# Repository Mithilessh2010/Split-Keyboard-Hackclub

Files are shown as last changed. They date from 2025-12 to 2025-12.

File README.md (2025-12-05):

# Split Keyboard Project

This repository contains the full design for my custom split keyboard, including the PCB, schematic, case files, and bill of materials. Everything needed to build or modify the keyboard is documented here in a clear and approachable format.

## Overview

The keyboard is built around the Seeed XIAO nRF52840 microcontroller, Kailh Choc low profile switches, SOD-123 diodes, and a simple two-piece 3D printed case. The goal of the project is to create a compact split keyboard that is straightforward to assemble and easy to modify.

## Images

All images for the project can be found in the Images folder.

### CAD View (Final, just unmated for clarity)
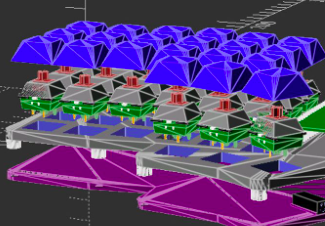
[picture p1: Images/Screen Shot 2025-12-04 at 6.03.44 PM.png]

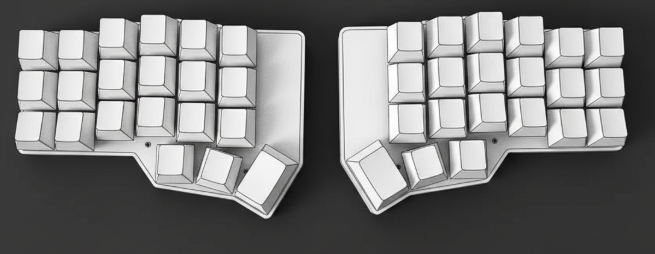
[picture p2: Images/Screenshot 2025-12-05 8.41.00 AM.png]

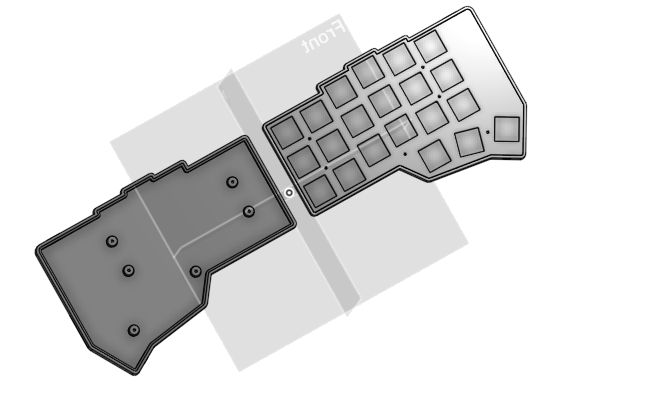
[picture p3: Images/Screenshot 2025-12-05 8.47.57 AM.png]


### PCB Layout
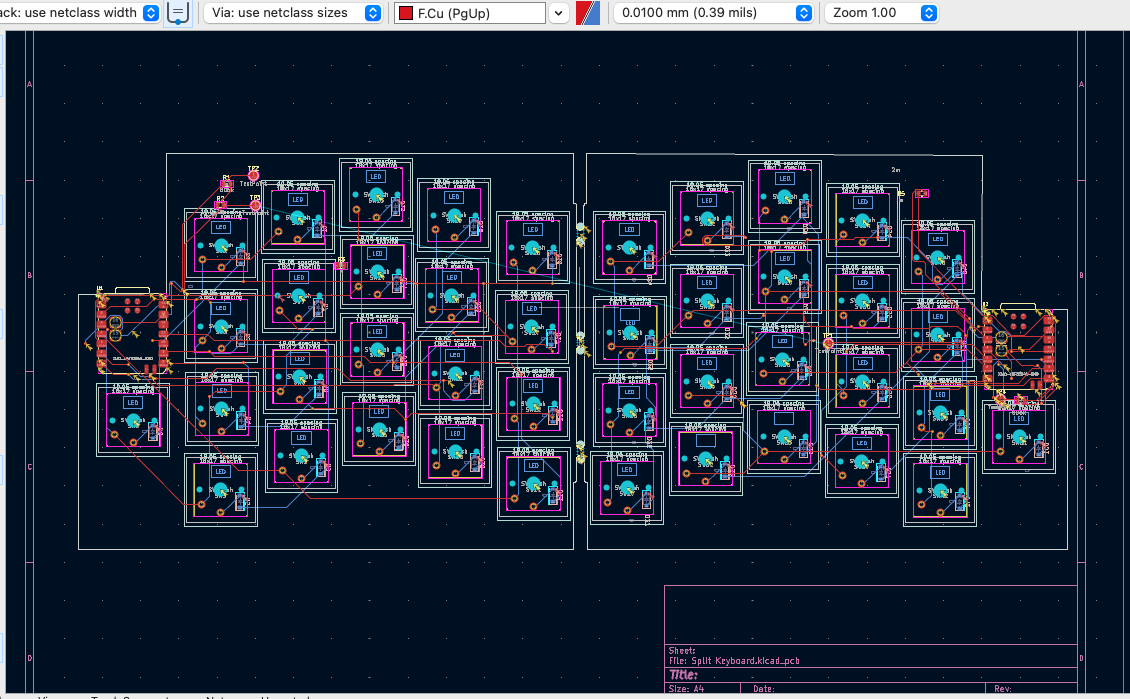
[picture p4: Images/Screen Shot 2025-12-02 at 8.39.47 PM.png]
PCB


### Schematics
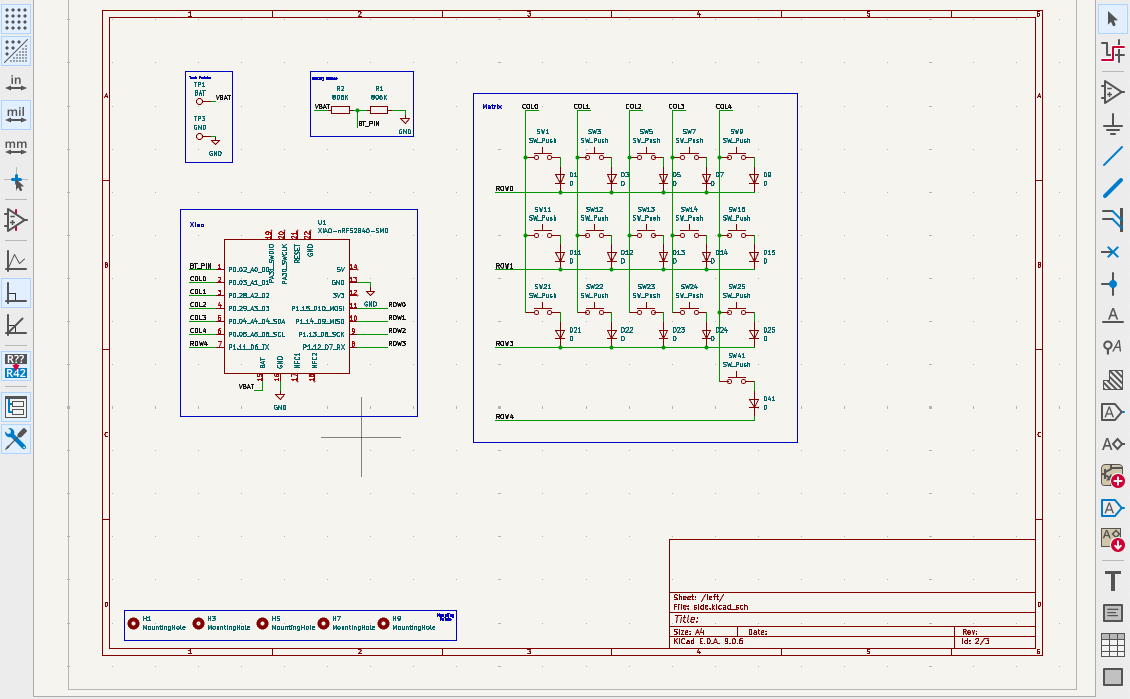
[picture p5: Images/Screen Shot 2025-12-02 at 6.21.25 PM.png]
Schematics


## Bill of Materials

Below is the full set of components used in the keyboard.

### BOM Table

| Category | Part Description | Footprint | Quantity |
|---|---|---|---|
| Resistors | 806k ohm | R_0805_2012Metric | 2 |
| | 2M ohm | R_0805_2012Metric | 2 |
| | R (0 ohm or jumper) | R_0805_2012Metric | 1 |
| Diodes | SOD-123 diode | D_SOD-123 | 42 |
| Microcontrollers | Seeed XIAO nRF52840 | modified-XIAO-nRF52840-SMD | 2 |
| Switches | Kailh Choc V1 switches | SW_choc_v1_1u | 41 |
| Test Points | Test pad | TestPoint_Pad_D2.0mm | 4 |

## 3D Printed Parts

The keyboard uses two printed case parts.

- Top case  
- Bottom case  

Both parts are sized so the PCB fits properly without forcing anything into place.

## Assembly Instructions

1. Install and solder all diodes first. These sit flat on the PCB.
2. Solder all resistors.
3. Insert and solder all Kailh Choc switches.
4. Attach both XIAO nRF52840 modules and verify each pin is properly soldered.
5. Inspect the board and test the key matrix.
6. Place the PCB into the printed case and complete the assembly.

## Cost Breakdown

### AliExpress Order
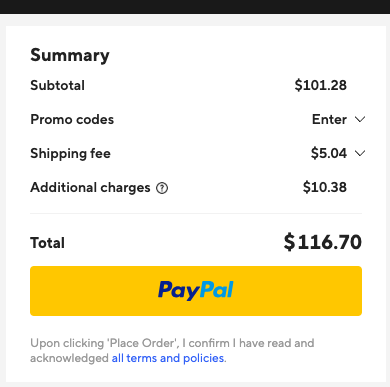
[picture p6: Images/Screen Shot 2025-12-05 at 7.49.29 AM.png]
ALIEXPRESSTOTAL

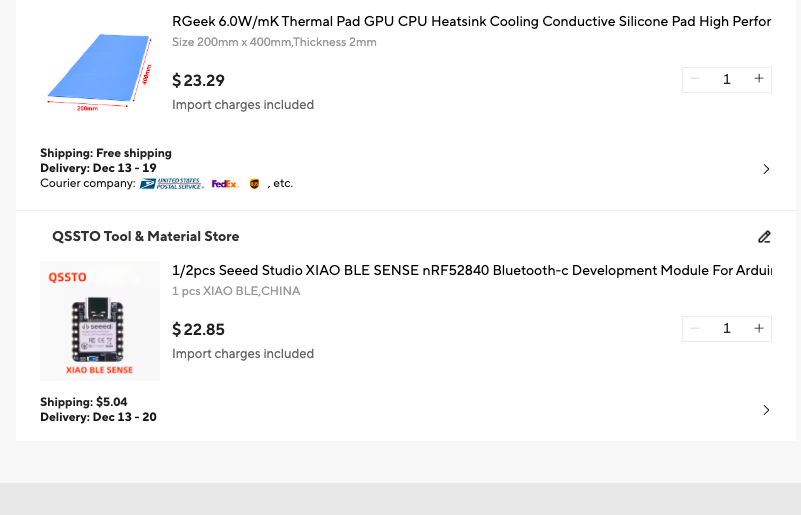
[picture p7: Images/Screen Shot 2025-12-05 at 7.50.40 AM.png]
ALIEXPRESS1

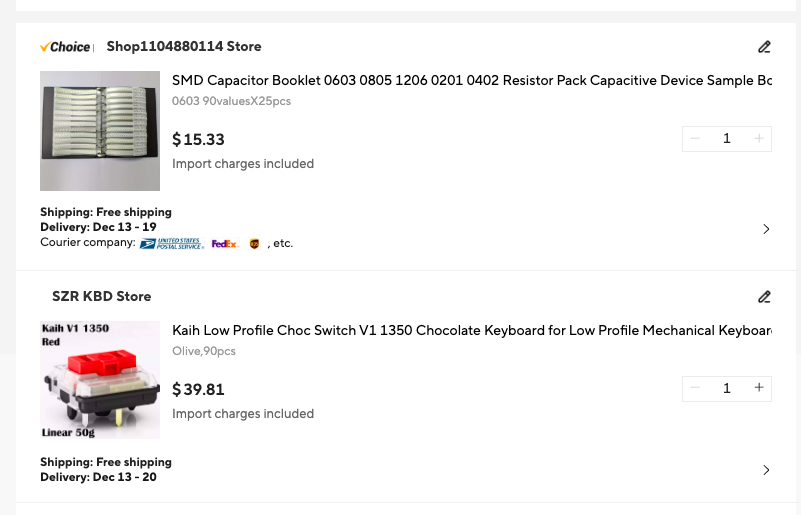
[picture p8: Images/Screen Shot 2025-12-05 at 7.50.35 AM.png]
ALIEXPRESS2


| Item | Quantity | Price |
|---|---|---|
| SMD Capacitor and Resistor Book (0603 0805 1206) | 1 | $15.33 |
| Kailh Choc V1 Switches (Olive, 90 pcs) | 1 | $39.81 |
| RGeek 6.0 W/mK Thermal Pad (200mm x 400mm, 2mm thick) | 1 | $23.29 |
| Seeed Studio XIAO BLE nRF52840 Module | 1 | $22.85 |
| Shipping for XIAO module | 1 | $5.04 |
| Additional charges (import, fees) | — | $10.38 |
| | | |
| Subtotal | | $101.28  |
| Shipping | | $5.04 |
| Additional charges | | $10.38 |
| **AliExpress total** | | **$116.70** |

### JLCPCB Order

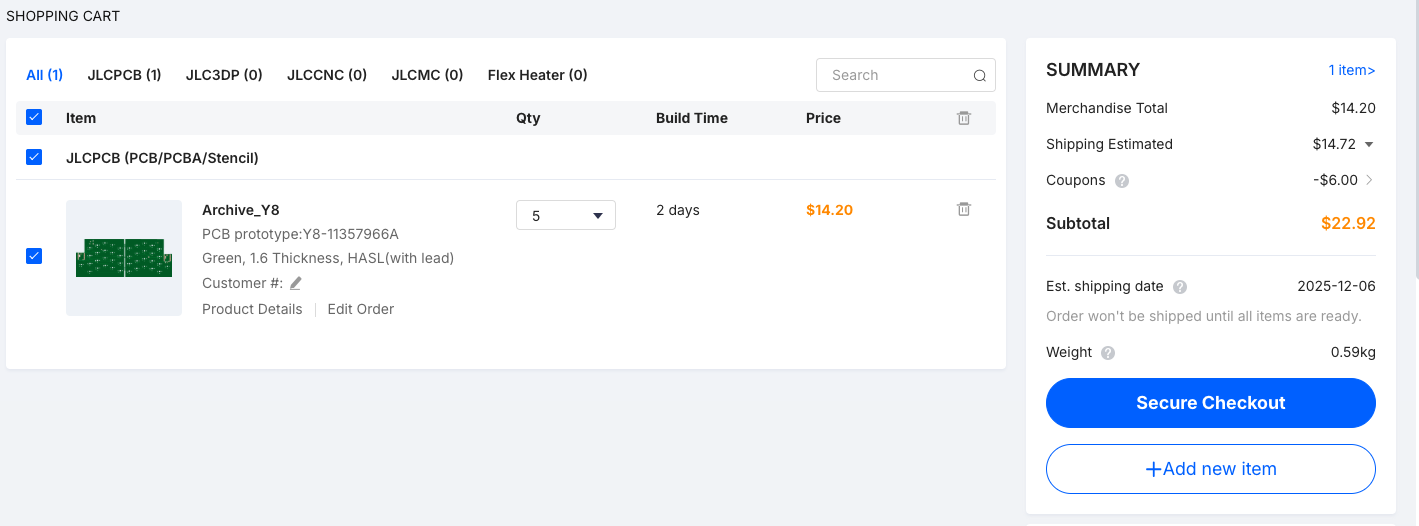
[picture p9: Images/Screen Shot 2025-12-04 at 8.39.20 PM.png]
JLPCB


| Item | Quantity | Price  |
|---|---|---|
| PCB prototype (5 boards) | 5 | $28.92 |

## Total Spent

| Source | Cost |
|---|---|
| AliExpress | $116.70  |
| JLCPCB | $28.92 |
| | |
| **Total spent** | **$145.62** |

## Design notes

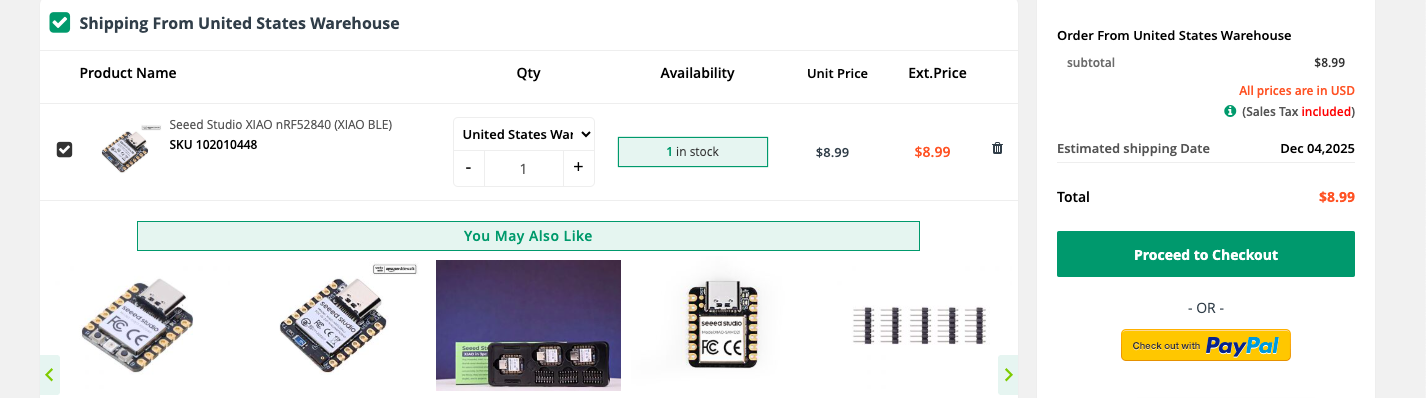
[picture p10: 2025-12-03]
Images/Screen Shot 2025-12-02 at 9.31.17 PM.png

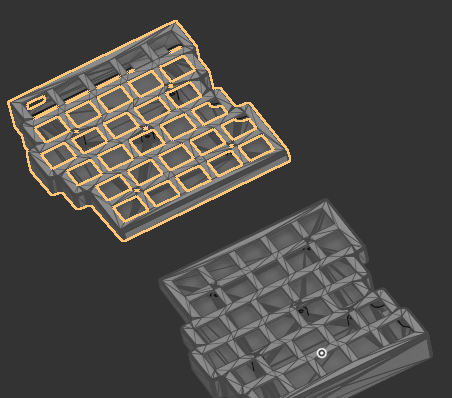
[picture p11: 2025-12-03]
Images/Screen Shot 2025-12-02 at 9.17.59 PM.png

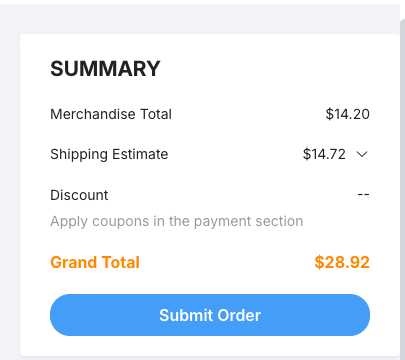
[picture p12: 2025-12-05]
Images/Screen Shot 2025-12-04 at 8.33.57 PM.png

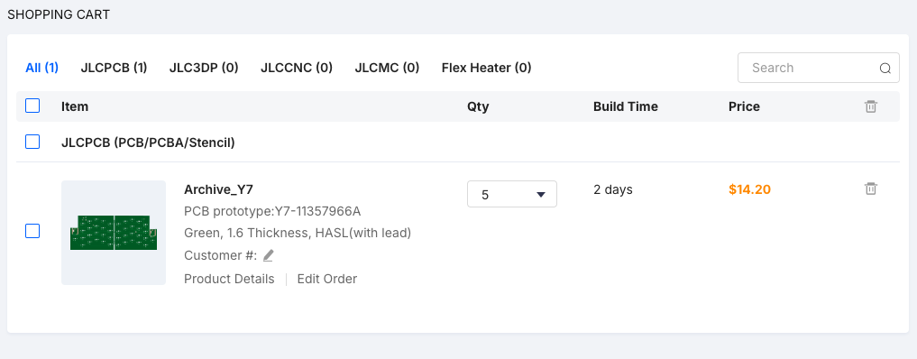
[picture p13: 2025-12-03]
Images/Screen Shot 2025-12-02 at 9.24.08 PM.png

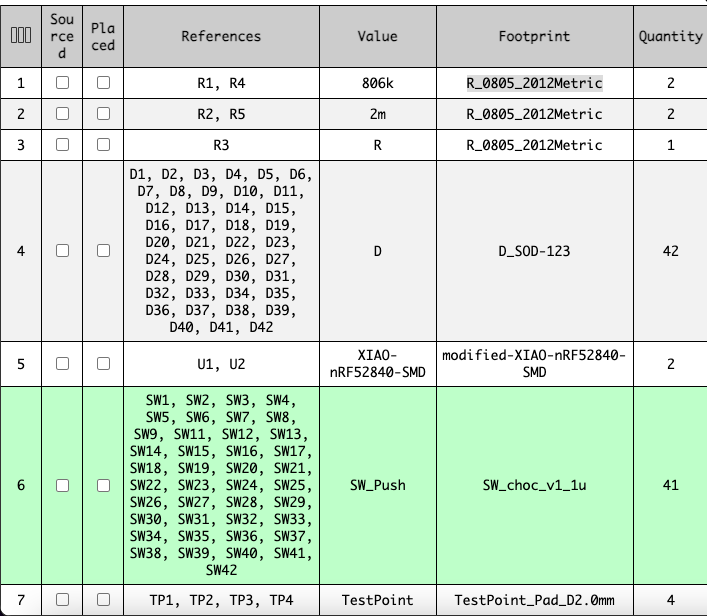
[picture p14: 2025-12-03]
Images/Screen Shot 2025-12-02 at 9.36.49 PM.png

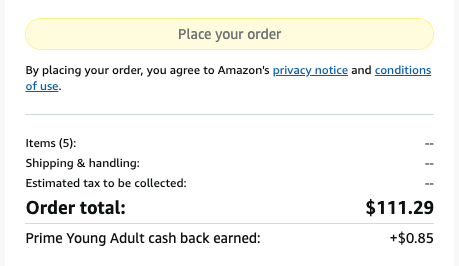
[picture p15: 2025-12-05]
Images/Screen Shot 2025-12-04 at 8.11.51 PM.png

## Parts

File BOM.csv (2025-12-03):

Id | Designator | Footprint | Quantity | Designation | Supplier and ref
1 | SW37,SW4,SW15,SW17,SW1,SW30,SW6,SW5,SW7,SW29,SW26,SW20,SW22,SW35,SW2,SW24,SW21,SW39,SW28,SW31,SW23,SW12,SW36,SW32,SW41,SW27,SW3,SW9,SW42,SW16,SW38,SW19,SW33,SW14,SW18,SW8,SW40,SW25,SW11,SW13,SW34 | SW_choc_v1_1u | 41 | SW_Push
2 | D9,D19,D40,D37,D28,D1,D42,D12,D16,D8,D18,D24,D25,D3,D15,D17,D2,D31,D5,D13,D10,D38,D21,D36,D34,D23,D11,D35,D41,D39,D14,D32,D33,D30,D29,D26,D27,D22,D20,D7,D6,D4 | D_SOD-123 | 42 | D
3 | TP2,TP4,TP1,TP3 | TestPoint_Pad_D2.0mm | 4 | TestPoint
4 | U2,U1 | modified-XIAO-nRF52840-SMD | 2 | XIAO-nRF52840-SMD
5 | R5,R2 | R_0805_2012Metric | 2 | 2m
6 | R4,R1 | R_0805_2012Metric | 2 | 806k
7 | R3 | R_0805_2012Metric | 1 | R

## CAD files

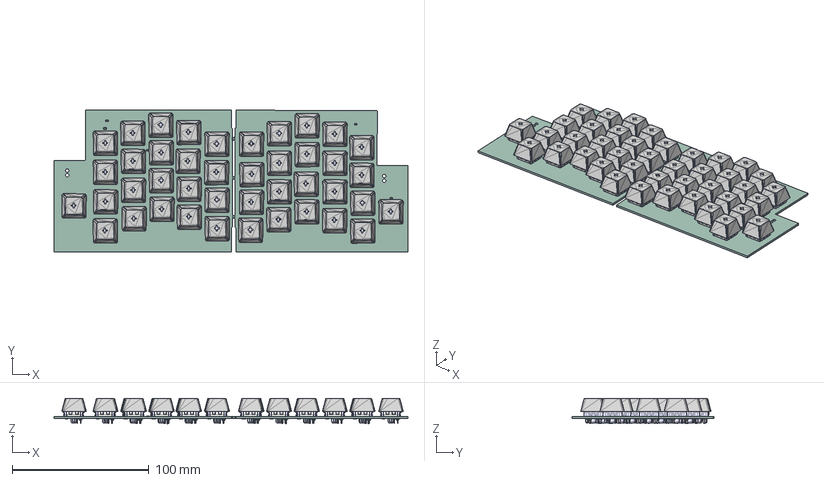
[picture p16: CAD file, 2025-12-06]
CAD/board.step
258.7 x 103.7 x 18.5 mm
Simple-CherryMX-Keycap v1 x 42
Housing x 42
ThickContact x 42
SpringContact x 42
Stem x 42
Lid x 42
R_0805_2012Metric x 5
D_SOD-123 x 42
best everdonet-splitkeep_PCB

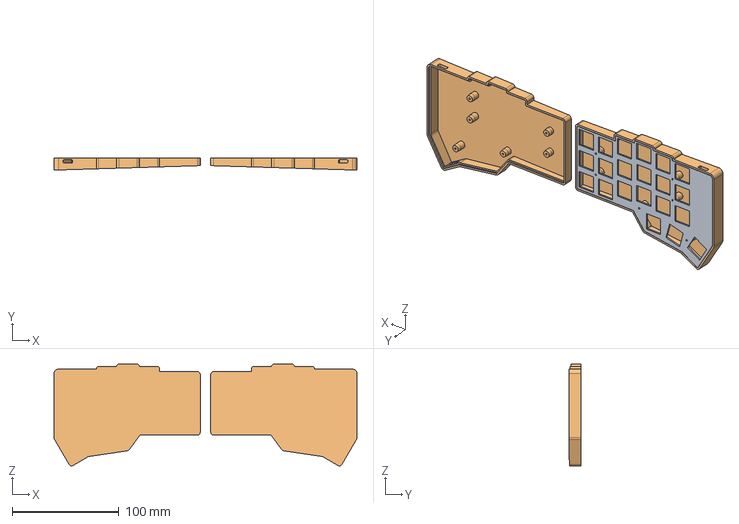
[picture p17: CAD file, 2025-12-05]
CAD/case.step
284.0 x 11.5 x 95.4 mm

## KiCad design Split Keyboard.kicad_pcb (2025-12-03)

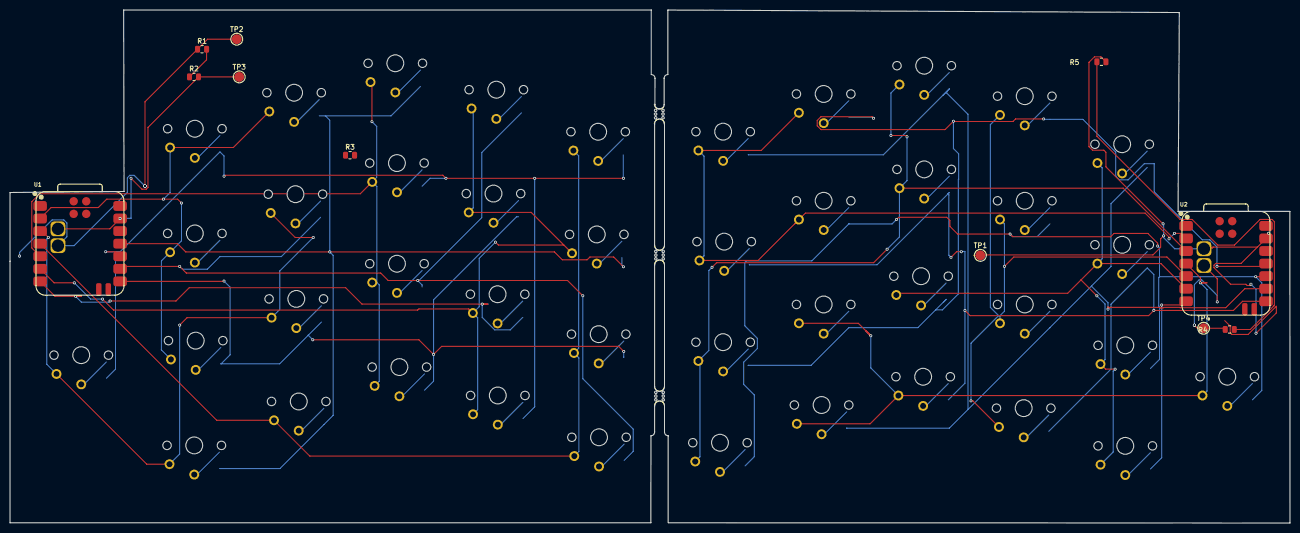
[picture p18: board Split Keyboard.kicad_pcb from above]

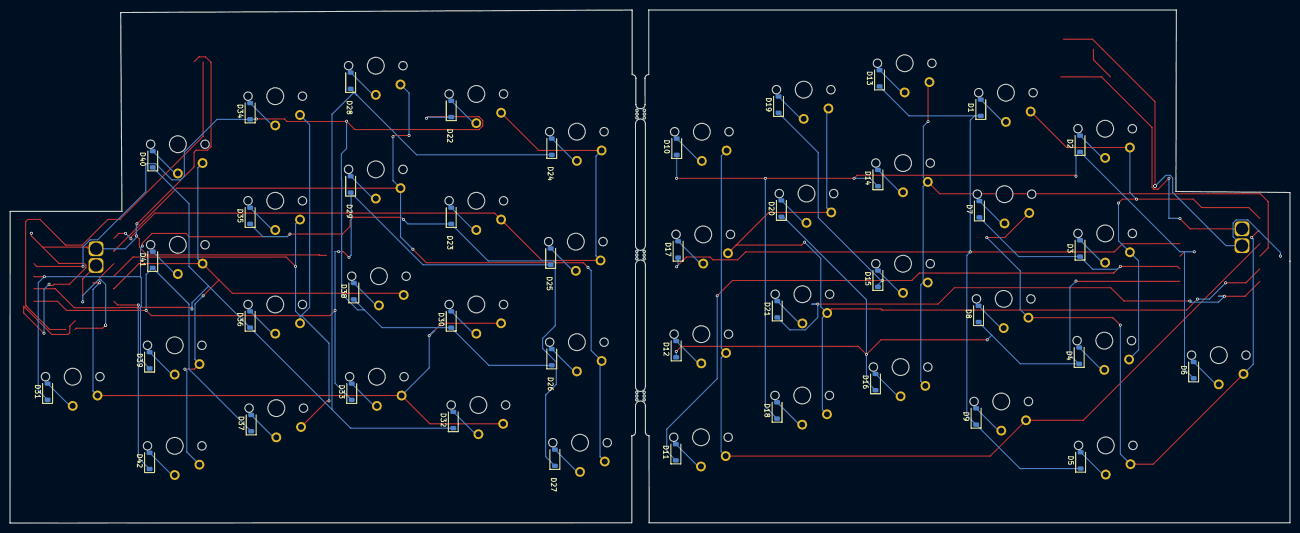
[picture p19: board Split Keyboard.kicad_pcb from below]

Board: 2 copper layers, 258.7 x 103.7 mm, 98 parts (42 on the bottom side), 67 nets.

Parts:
BO1, BO2, BO3: break off; mouse-bite-2mm-slot
D1, D2, D3, D4, D5, D6, D7, D8, D9, D10, D11, D12, D13, D14, D15, D16, D17, D18, D19, D20, D21, D22, D23, D24, D25, D26, D27, D28, D29, D30, D31, D32, D33, D34, D35, D36, D37, D38, D39, D40, D41, D42: D; D_SOD-123
R1, R4: 806k; R_0805_2012Metric
R2, R5: 2m; R_0805_2012Metric
R3: R; R_0805_2012Metric
SW1, SW2, SW3, SW4, SW5, SW6, SW7, SW8, SW9, SW10, SW11, SW12, SW13, SW14, SW15, SW16, SW17, SW18, SW19, SW20, SW21, SW22, SW23, SW24, SW25, SW26, SW27, SW28, SW29, SW30, SW31, SW32, SW33, SW34, SW35, SW36, SW37, SW38, SW39, SW40, SW41, SW42: SW_Push; SW_choc_v1_1u
TP1, TP2, TP3, TP4: TestPoint; TestPoint_Pad_D2.0mm
U1, U2: XIAO-nRF52840-SMD; modified-XIAO-nRF52840-SMD

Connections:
/left/BT-PIN: R1.2, R2.1
/left/C0: SW1.1, SW2.1, SW3.1, SW4.1, U1.2 (P0.03_A1_D1)
/left/C1: SW5.1, SW6.1, SW7.1, SW8.1, U1.3 (P0.28_A2_D2)
/left/C2: SW9.1, SW10.1, SW11.1, SW12.1, U1.4 (P0.29_A3_D3)
/left/C3: SW13.1, SW14.1, SW15.1, SW16.1, U1.5 (P0.04_A4_D4_SDA)
/left/C4: SW17.1, SW18.1, SW19.1, SW20.1, SW21.1, U1.6 (P0.05_A5_D5_SCL)
/left/R0: D1.1 (K), D5.1 (K), D9.1 (K), D13.1 (K), D17.1 (K), U1.11 (P1.15_D10_MOSI)
/left/R1: D2.1 (K), D6.1 (K), D10.1 (K), D14.1 (K), D18.1 (K), U1.10 (P1.14_D9_MISO)
/left/R4: D21.1 (K), U1.7 (P1.11_D6_TX)
/left/Ro2: D3.1 (K), D7.1 (K), D11.1 (K), D15.1 (K), D19.1 (K), U1.9 (P1.13_D8_SCK)
/left/Ro3: D4.1 (K), D8.1 (K), D12.1 (K), D16.1 (K), D20.1 (K), U1.8 (P1.12_D7_RX)
/left/VBAT: R1.1, TP2.1, U1.15 (BAT)
/right/BT-PIN: R4.2, R5.1
/right/C0: SW22.1, SW23.1, SW24.1, SW25.1, U2.2 (P0.03_A1_D1)
/right/C1: SW26.1, SW27.1, SW28.1, SW29.1, U2.3 (P0.28_A2_D2)
/right/C2: SW30.1, SW31.1, SW32.1, SW33.1, U2.4 (P0.29_A3_D3)
/right/C3: SW34.1, SW35.1, SW36.1, SW37.1, U2.5 (P0.04_A4_D4_SDA)
/right/C4: SW38.1, SW39.1, SW40.1, SW41.1, SW42.1, U2.6 (P0.05_A5_D5_SCL)
/right/R0: D22.1 (K), D26.1 (K), D30.1 (K), D34.1 (K), D38.1 (K), U2.11 (P1.15_D10_MOSI)
/right/R1: D23.1 (K), D27.1 (K), D31.1 (K), D35.1 (K), D39.1 (K), U2.10 (P1.14_D9_MISO)
/right/R4: D42.1 (K), U2.7 (P1.11_D6_TX)
/right/Ro2: D24.1 (K), D28.1 (K), D32.1 (K), D36.1 (K), D40.1 (K), U2.9 (P1.13_D8_SCK)
/right/Ro3: D25.1 (K), D29.1 (K), D33.1 (K), D37.1 (K), D41.1 (K), U2.8 (P1.12_D7_RX)
/right/VBAT: R4.1, TP4.1, U2.15 (BAT)
GND: R2.2, R5.2, TP1.1, TP3.1, U1.13 (GND), U1.16 (GND), U2.13 (GND), U2.16 (GND)
unnamed: D1.2 (A), SW1.2
unnamed: D2.2 (A), SW2.2
unnamed: D3.2 (A), SW3.2
unnamed: D4.2 (A), SW4.2
unnamed: D5.2 (A), SW5.2
unnamed: D6.2 (A), SW6.2
unnamed: D7.2 (A), SW7.2
unnamed: D8.2 (A), SW8.2
unnamed: D9.2 (A), SW9.2
unnamed: D10.2 (A), SW10.2
unnamed: D11.2 (A), SW11.2
unnamed: D12.2 (A), SW12.2
unnamed: D13.2 (A), SW13.2
unnamed: D14.2 (A), SW14.2
unnamed: D15.2 (A), SW15.2
unnamed: D16.2 (A), SW16.2
unnamed: D17.2 (A), SW17.2
unnamed: D18.2 (A), SW18.2
unnamed: D19.2 (A), SW19.2
unnamed: D20.2 (A), SW20.2
unnamed: D21.2 (A), SW21.2
unnamed: D22.2 (A), SW22.2
unnamed: D23.2 (A), SW23.2
unnamed: D24.2 (A), SW24.2
unnamed: D25.2 (A), SW25.2
unnamed: D26.2 (A), SW26.2
unnamed: D27.2 (A), SW27.2
unnamed: D28.2 (A), SW28.2
unnamed: D29.2 (A), SW29.2
unnamed: D30.2 (A), SW30.2
unnamed: D31.2 (A), SW31.2
unnamed: D32.2 (A), SW32.2
unnamed: D33.2 (A), SW33.2
unnamed: D34.2 (A), SW34.2
unnamed: D35.2 (A), SW35.2
unnamed: D36.2 (A), SW36.2
unnamed: D37.2 (A), SW37.2
unnamed: D38.2 (A), SW38.2
unnamed: D39.2 (A), SW39.2
unnamed: D40.2 (A), SW40.2
unnamed: D41.2 (A), SW41.2
unnamed: D42.2 (A), SW42.2

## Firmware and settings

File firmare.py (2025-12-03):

import board
from kmk.kmk_keyboard import KMKKeyboard
from kmk.keys import KC
from kmk.scanners import DiodeMatrix

keyboard = KMKKeyboard()

row_pins = [board.D0, board.D1, board.D2, board.D3, board.D4, board.D5]
col_pins = [board.D6, board.D7, board.D8, board.D9, board.D10, board.D11, board.D12]

keyboard.matrix = DiodeMatrix(row_pins=row_pins, column_pins=col_pins, diode_orientation=DiodeMatrix.ROW2COL)

keyboard.keymap = [[
    KC.ESC, KC.F1, KC.F2, KC.F3, KC.F4, KC.F5, KC.F6,
    KC.TAB, KC.Q, KC.W, KC.E, KC.R, KC.T, KC.Y,
    KC.LCTRL, KC.A, KC.S, KC.D, KC.F, KC.G, KC.H,
    KC.LSHIFT, KC.Z, KC.X, KC.C, KC.V, KC.B, KC.N,
    KC.SPC, KC.M, KC.COMMA, KC.DOT, KC.SLASH, KC.RALT, KC.RCTRL,
    KC.LEFT, KC.DOWN, KC.UP, KC.RIGHT, KC.HOME, KC.END, KC.ENTER
]]

if __name__ == '__main__':
    keyboard.go()

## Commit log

2025-12-05 Change CAD image to direct URL link
    Updated CAD image link to use a direct URL.
2025-12-05 Revise README for clarity and formatting
    Updated the README for clarity and consistency in language, improved formatting for BOM and assembly instructions.
2025-12-05 Update CAD View description and JLCPCB image
2025-12-05 Add CAD images with links to README
    Added additional CAD images with links to GitHub.
